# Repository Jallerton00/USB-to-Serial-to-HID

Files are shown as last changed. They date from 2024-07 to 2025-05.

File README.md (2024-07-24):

# USB to Serial to HID

A tool which emulates a HID device (keyboard/mouse) to control one PC from another.

This can be used as the Keyboard and Mouse in a KVM - either an IP KVM (like PiKVM) or a laptop KVM.

## Images

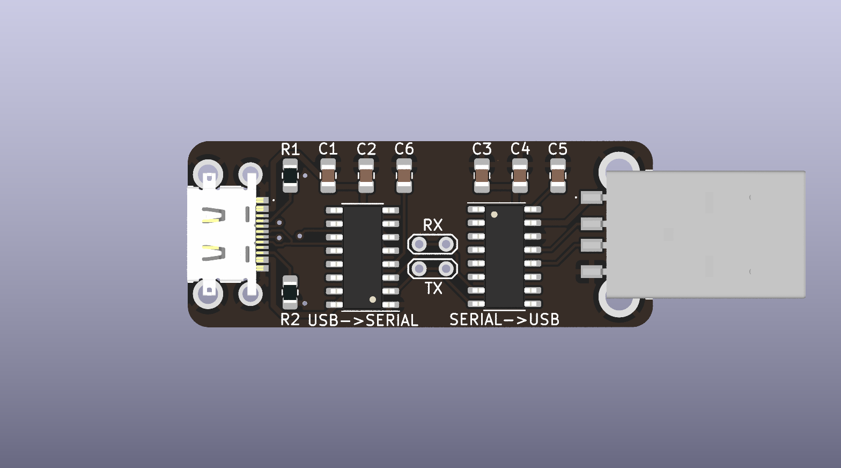
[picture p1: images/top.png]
Top

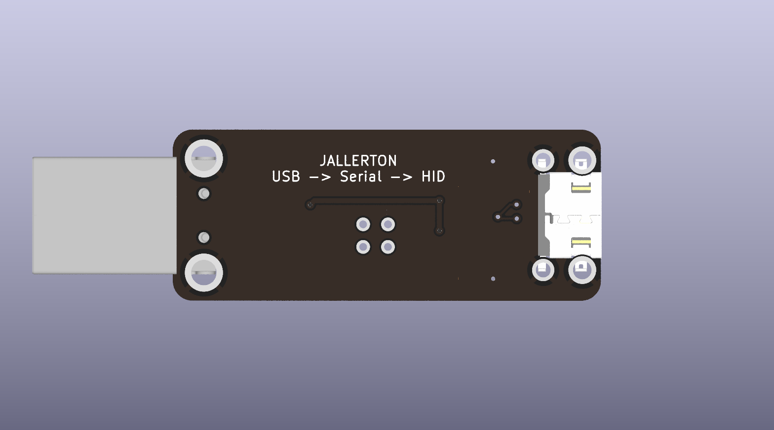
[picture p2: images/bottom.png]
Bottom


## Usage

### PiKVM

The [PiKVM](https://github.com/pikvm/pikvm) project makes use of a Raspberry Pi to provide KVM over IP. Simply add an HDMI capture device and some way to do keyboard/mouse control. The PiKVM team provides a couple of ways of doing this, but this project is an alternative to it.

#### Set up

You need to be able to set the override.yaml in a PiKVM install. This typically means:

- Connect via SSH or the web terminal (`su -` to switch to root user)
- Enable read/write - `rw`
- Add the below config section - `nano /etc/kvmd/override.yaml`
    - [More information about the config files](https://docs.pikvm.org/first_steps/#structure-of-configuration-files)
- Make readonly - `ro`

```yaml
kvmd:
    hid:
        type: ch9329
```

#### Laptop KVM

There exists a project which uses a piece of custom hardware to turn a laptop into a KVM - [Openterface](https://openterface.com/) - which means you can use your laptop as a PC crash cart. This project can be used as a cheaper alternative.

With a USB HDMI capture device (like [this](https://www.amazon.co.uk/UGREEN-Thunderbolt-Compatible-Camera-iPad-Laptop-Phone/dp/B0CFQ2BMPZ)), this hardware and a [fork of the Openterface software](https://github.com/Jallerton00/Openterface_QT), you can mimic most of what the Openterface project can achieve.

This is not feature complete - the original project provides more options for host software; a USB port swhich which can be switched between host and target & integrated HDMI capture - but may be a decent alternative for some.

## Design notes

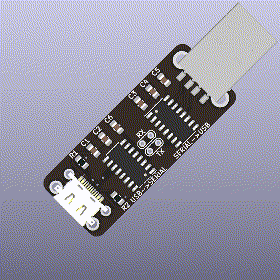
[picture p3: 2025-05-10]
images/rotating.gif

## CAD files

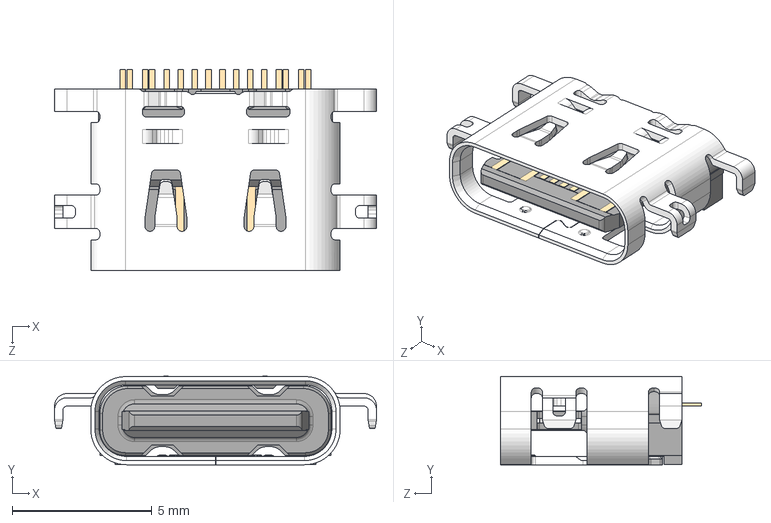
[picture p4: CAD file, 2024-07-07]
Farnell/USB4520-03-1-A.stp
11.5 x 3.17 x 7.20 mm
Shell mid 2.1 with spring
Housing mid 2.10

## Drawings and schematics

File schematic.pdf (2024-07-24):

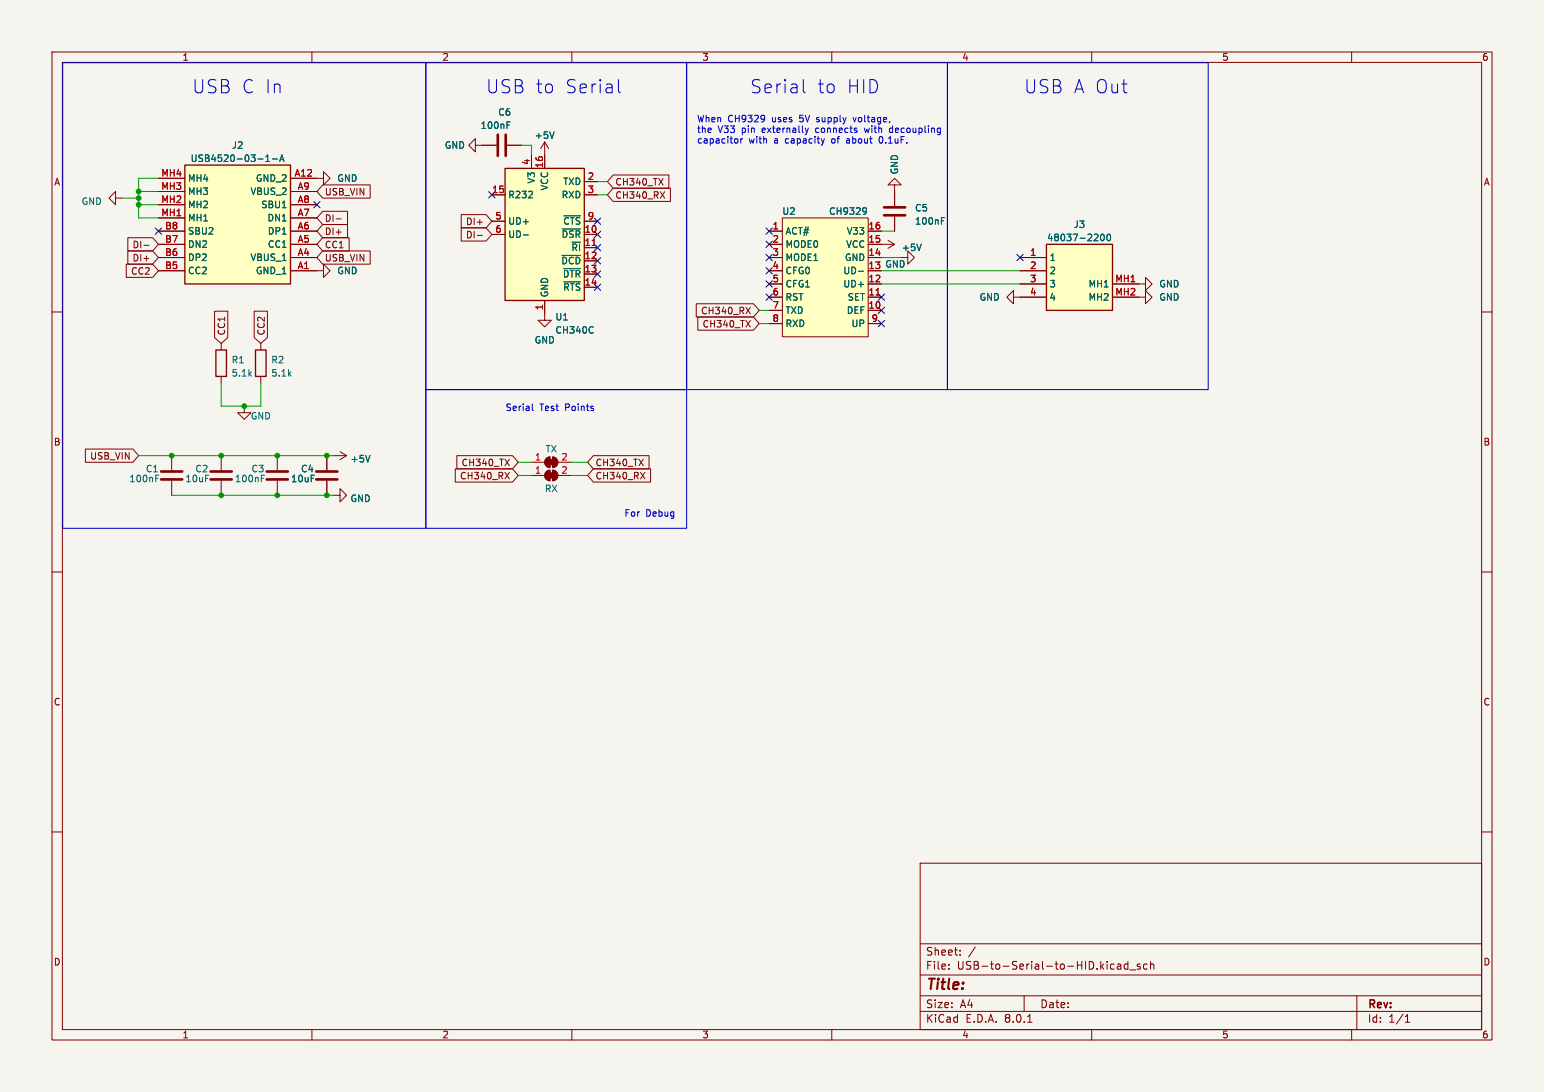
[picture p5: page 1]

When CH9329 uses 5V supply voltage,

4 UD+ 5 UD- 6 ~{CTS}9 U1 CH340C GND

1 ~{DSR} 10 ~{RI} 11 ~{DCD} 12 ~{DTR} 13 ~{RTS} 14 R232 15 VCC 16 TXD 2 RXD 3 V3

Id: 1/1 Title: File: USB-to-Serial-to-HID.kicad_sch Sheet: /

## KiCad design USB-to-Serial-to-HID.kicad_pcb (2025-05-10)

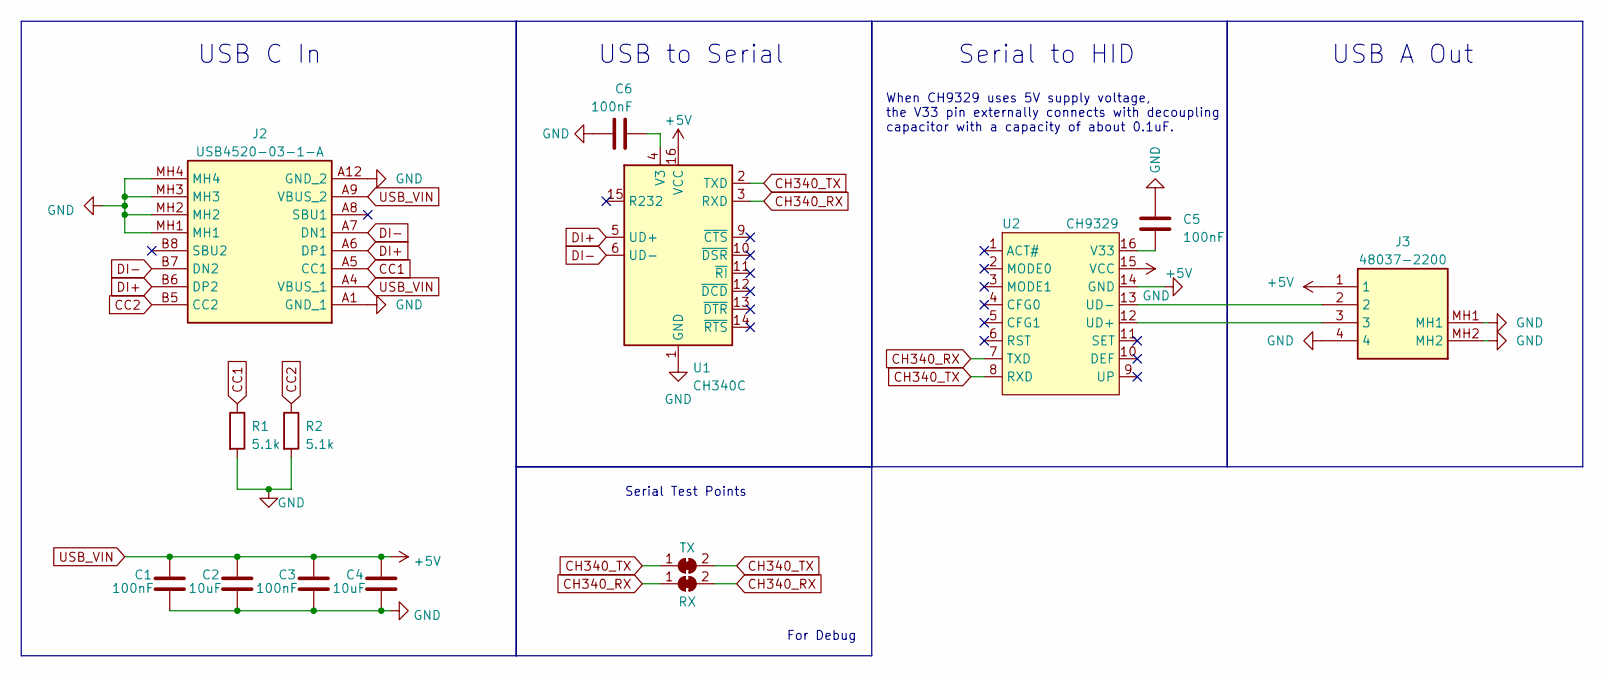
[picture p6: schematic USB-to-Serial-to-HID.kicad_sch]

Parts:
C1, C3, C5, C6: 100nF; C_0805_2012Metric_Pad1.18x1.45mm_HandSolder
C2, C4: 10uF; C_0805_2012Metric_Pad1.18x1.45mm_HandSolder
J2: USB4520-03-1-A; USB4520031A; Manufacturer_Part_Number USB4520-03-1-A
J3: 48037-2200; 480372200; Manufacturer_Part_Number 48037-2200
JP1: TX; TestPoint_2Pads_Pitch2.54mm_Drill0.8mm
JP2: RX; TestPoint_2Pads_Pitch2.54mm_Drill0.8mm
R1, R2: 5.1k; R_0805_2012Metric_Pad1.20x1.40mm_HandSolder
U1: CH340C; SOIC-16_3.9x9.9mm_P1.27mm
U2: CH9329; SOIC-16_3.9x9.9mm_P1.27mm

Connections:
CC1: J2.A5 (CC1), R1.1
CC2: J2.B5 (CC2), R2.1
CH340_RX: JP2.1 (A), JP2.2 (B), U1.3 (RXD), U2.7 (TXD)
CH340_TX: JP1.1 (A), JP1.2 (B), U1.2 (TXD), U2.8 (RXD)
DI+: J2.A6 (DP1), J2.B6 (DP2), U1.5 (UD+)
DI-: J2.A7 (DN1), J2.B7 (DN2), U1.6 (UD-)
GND: C1.2, C2.2, C3.2, C4.2, C5.1, C6.1, J2.A1 (GND_1), J2.A12 (GND_2), J2.MH1, J2.MH2, J2.MH3, J2.MH4, J3.4, J3.MH1, J3.MH2, R1.2, R2.2, U1.1 (GND), U2.14 (GND)
unnamed: C6.2, U1.4 (V3)
unnamed: J3.3, U2.12 (UD+)
unnamed: J3.2, U2.13 (UD-)
unnamed: C5.2, U2.16 (V33)
USB_VIN: C1.1, C2.1, C3.1, C4.1, J2.A4 (VBUS_1), J2.A9 (VBUS_2), J3.1, U1.16 (VCC), U2.15 (VCC)

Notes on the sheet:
Serial Test Points
USB C In
When CH9329 uses 5V supply voltage, the V33 pin externally connects with decoupling capacitor with a capacity of about 0.1uF.
Serial to HID
USB A Out
USB to Serial
For Debug

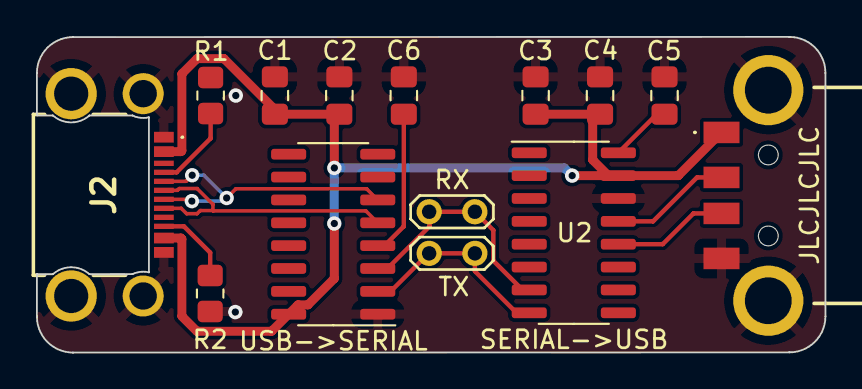
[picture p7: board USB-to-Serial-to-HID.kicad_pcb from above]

Board: 2 copper layers, 43.8 x 17.5 mm, 14 parts (0 on the bottom side), 12 nets.

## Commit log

2024-07-07 Initial Commit (After adding caps)
    [USB HID-B_Cu.gbr, USB HID-B_Mask.gbr, USB HID-B_Paste.gbr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]
2024-07-07 Update images, schematic and gerbers
2024-07-07 Rename to USB-to-Serial-to-HID
    [USB HID-B_Cu.gbr, USB HID-B_Mask.gbr, USB HID-B_Paste.gbr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]
2024-07-07 More renaming
    [USB-to-Serial-to-HID.kicad_pcb]
2024-07-08 Move to CH340C
    [USB-to-Serial-to-HID.kicad_pcb, USB-to-Serial-to-HID.kicad_sch]
2024-07-09 Make shape path relative
    [USB-to-Serial-to-HID.kicad_pcb]
2024-07-09 Make USB step file path relative
    [USB-to-Serial-to-HID.kicad_pcb]
2024-07-09 Update 480372200.kicad_mod and PCB
    [USB-to-Serial-to-HID.kicad_pcb]
2024-07-09 Update PCB - USB Step File
    [USB-to-Serial-to-HID.kicad_pcb]
2025-05-10 Update to use target 5V as well as host 5V
    [USB-to-Serial-to-HID.kicad_pcb, USB-to-Serial-to-HID.kicad_sch]
